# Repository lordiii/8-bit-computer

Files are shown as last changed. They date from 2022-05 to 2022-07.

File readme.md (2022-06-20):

# Custom 8 Bit Computer

The KiCad project in this folder contains a high-level view of the Computer using KiCad's subschematics. 

_TODO: High-Level View as PDF_

### Folder Structure
- [Parts](parts/): Contains KiCad 5 schematics of each of the computers parts.
- [Instructions](instructions/): FPGA implementation of the instruction decoder, as well as the list of instructions 

### Credits
- [Ben Eater](https://eater.net). Some parts are based on his 8 Bit Computer

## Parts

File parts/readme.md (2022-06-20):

### TODO
This folder will contain a list of each sub-part and a brief description

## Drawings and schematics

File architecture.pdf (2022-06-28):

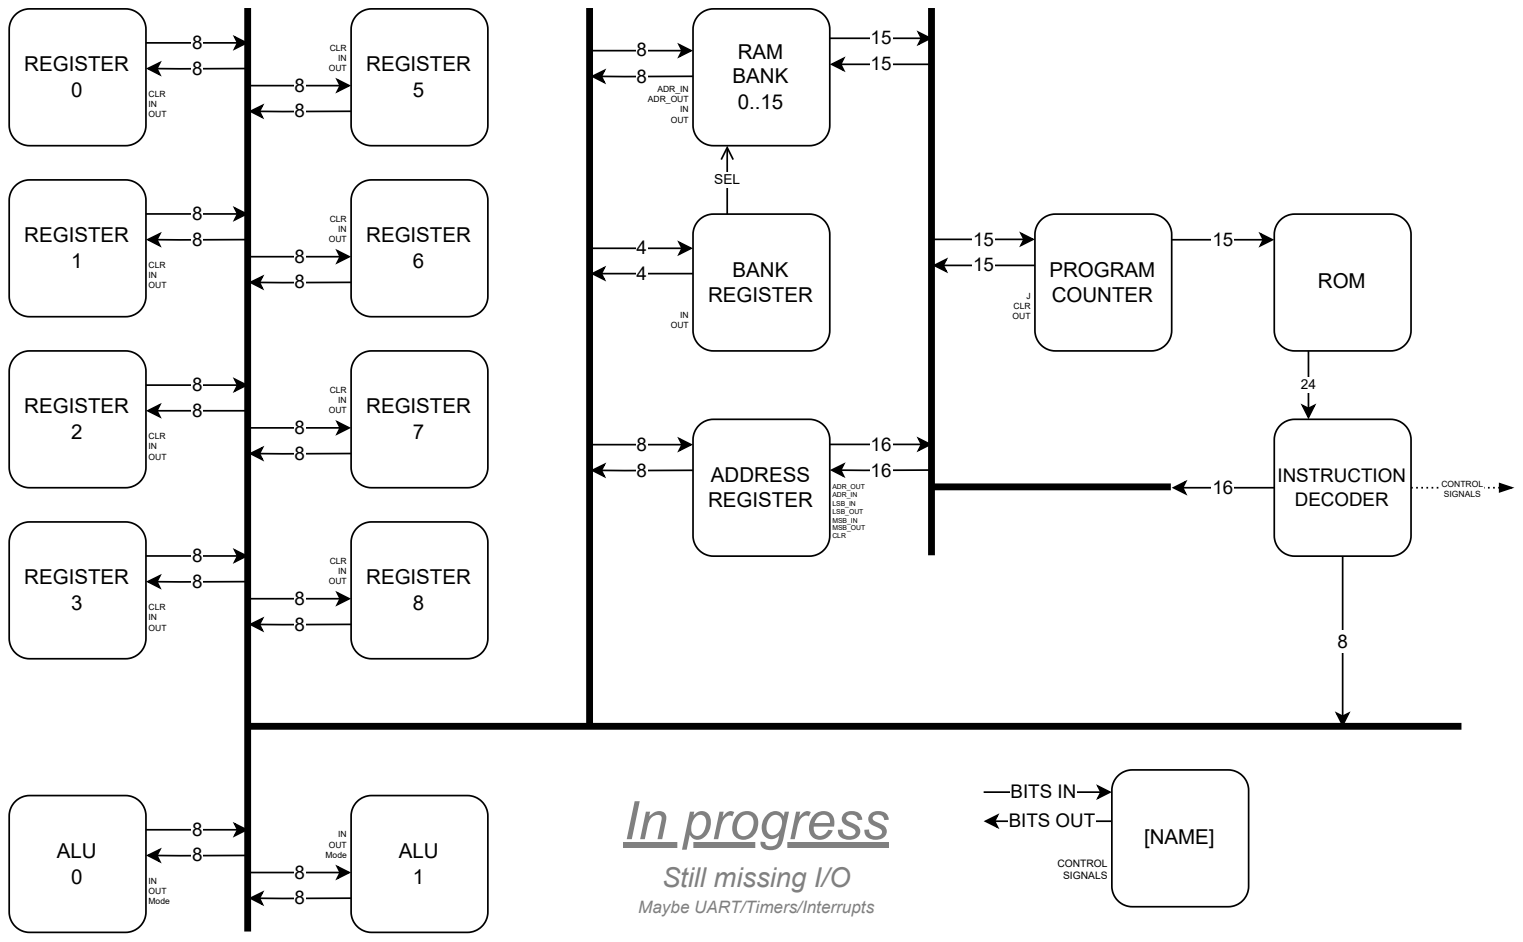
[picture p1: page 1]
REGISTER 0; REGISTER 1; REGISTER 2; REGISTER 5; REGISTER 6; REGISTER 7; REGISTER 3; REGISTER 8; ALU 0; ALU 1; CLR IN OUT; IN OUT; RAM BANK 0..15; IN OUT Mode; INSTRUCTION DECODER; In progress; ADDRESS REGISTER; ADR_OUT ADR_IN LSB_IN LSB_OUT MSB_IN MSB_OUT CLR; [NAME]; CONTROL SIGNALS; BITS IN BITS OUT; BANK; REGISTER; ROM; ADR_IN ADR_OUT IN OUT; SEL; J CLR OUT; PROGRAM COUNTER

Still missing I/O
Maybe UART/Timers/Interrupts

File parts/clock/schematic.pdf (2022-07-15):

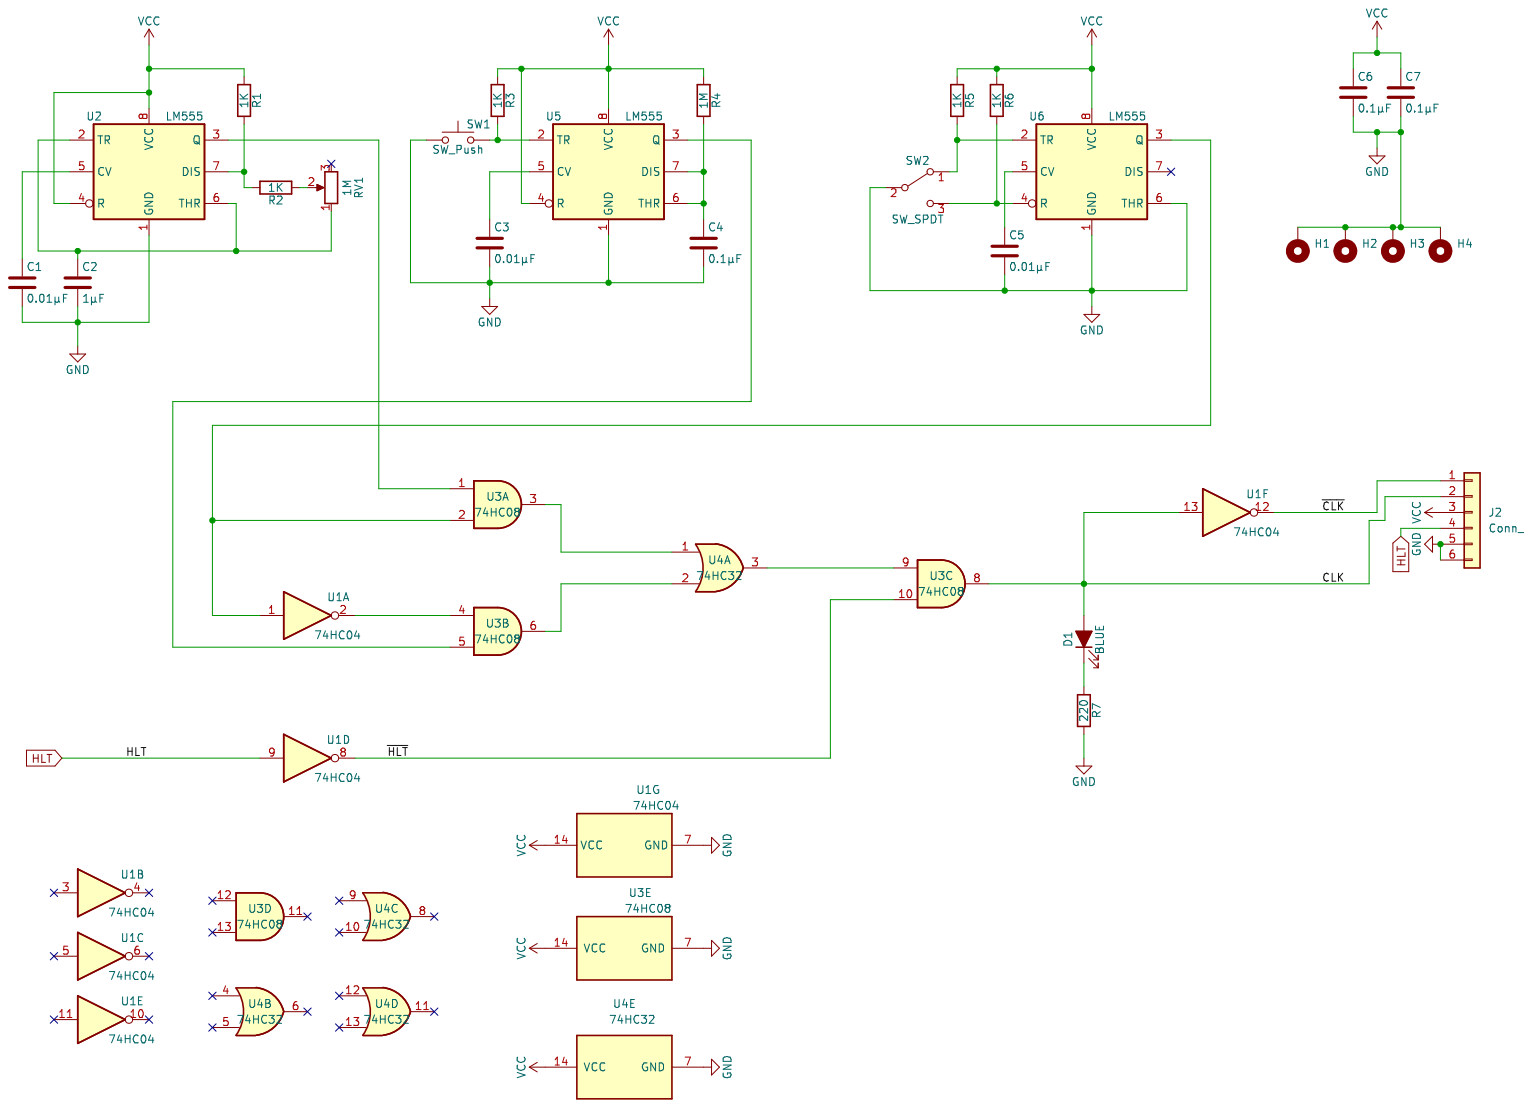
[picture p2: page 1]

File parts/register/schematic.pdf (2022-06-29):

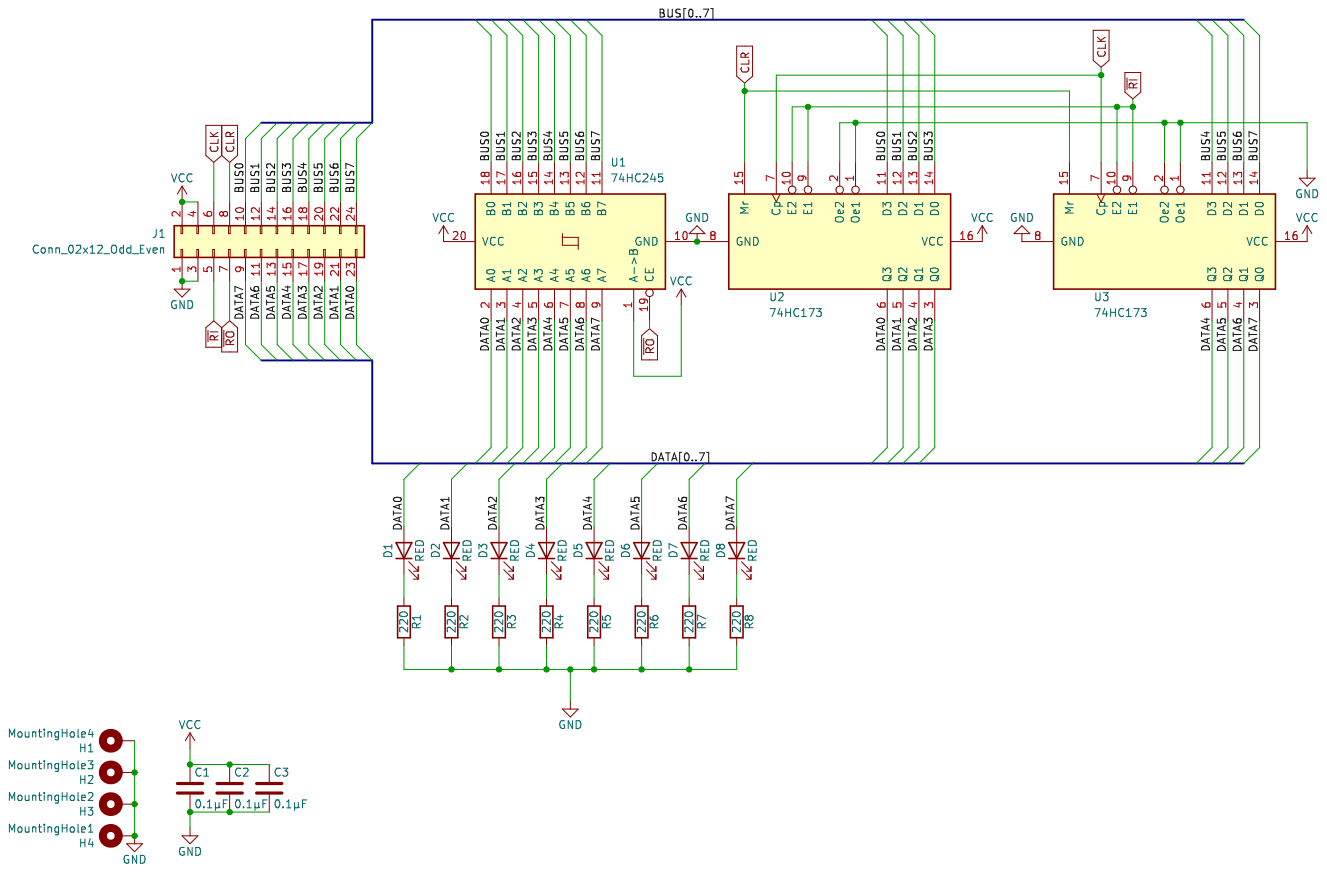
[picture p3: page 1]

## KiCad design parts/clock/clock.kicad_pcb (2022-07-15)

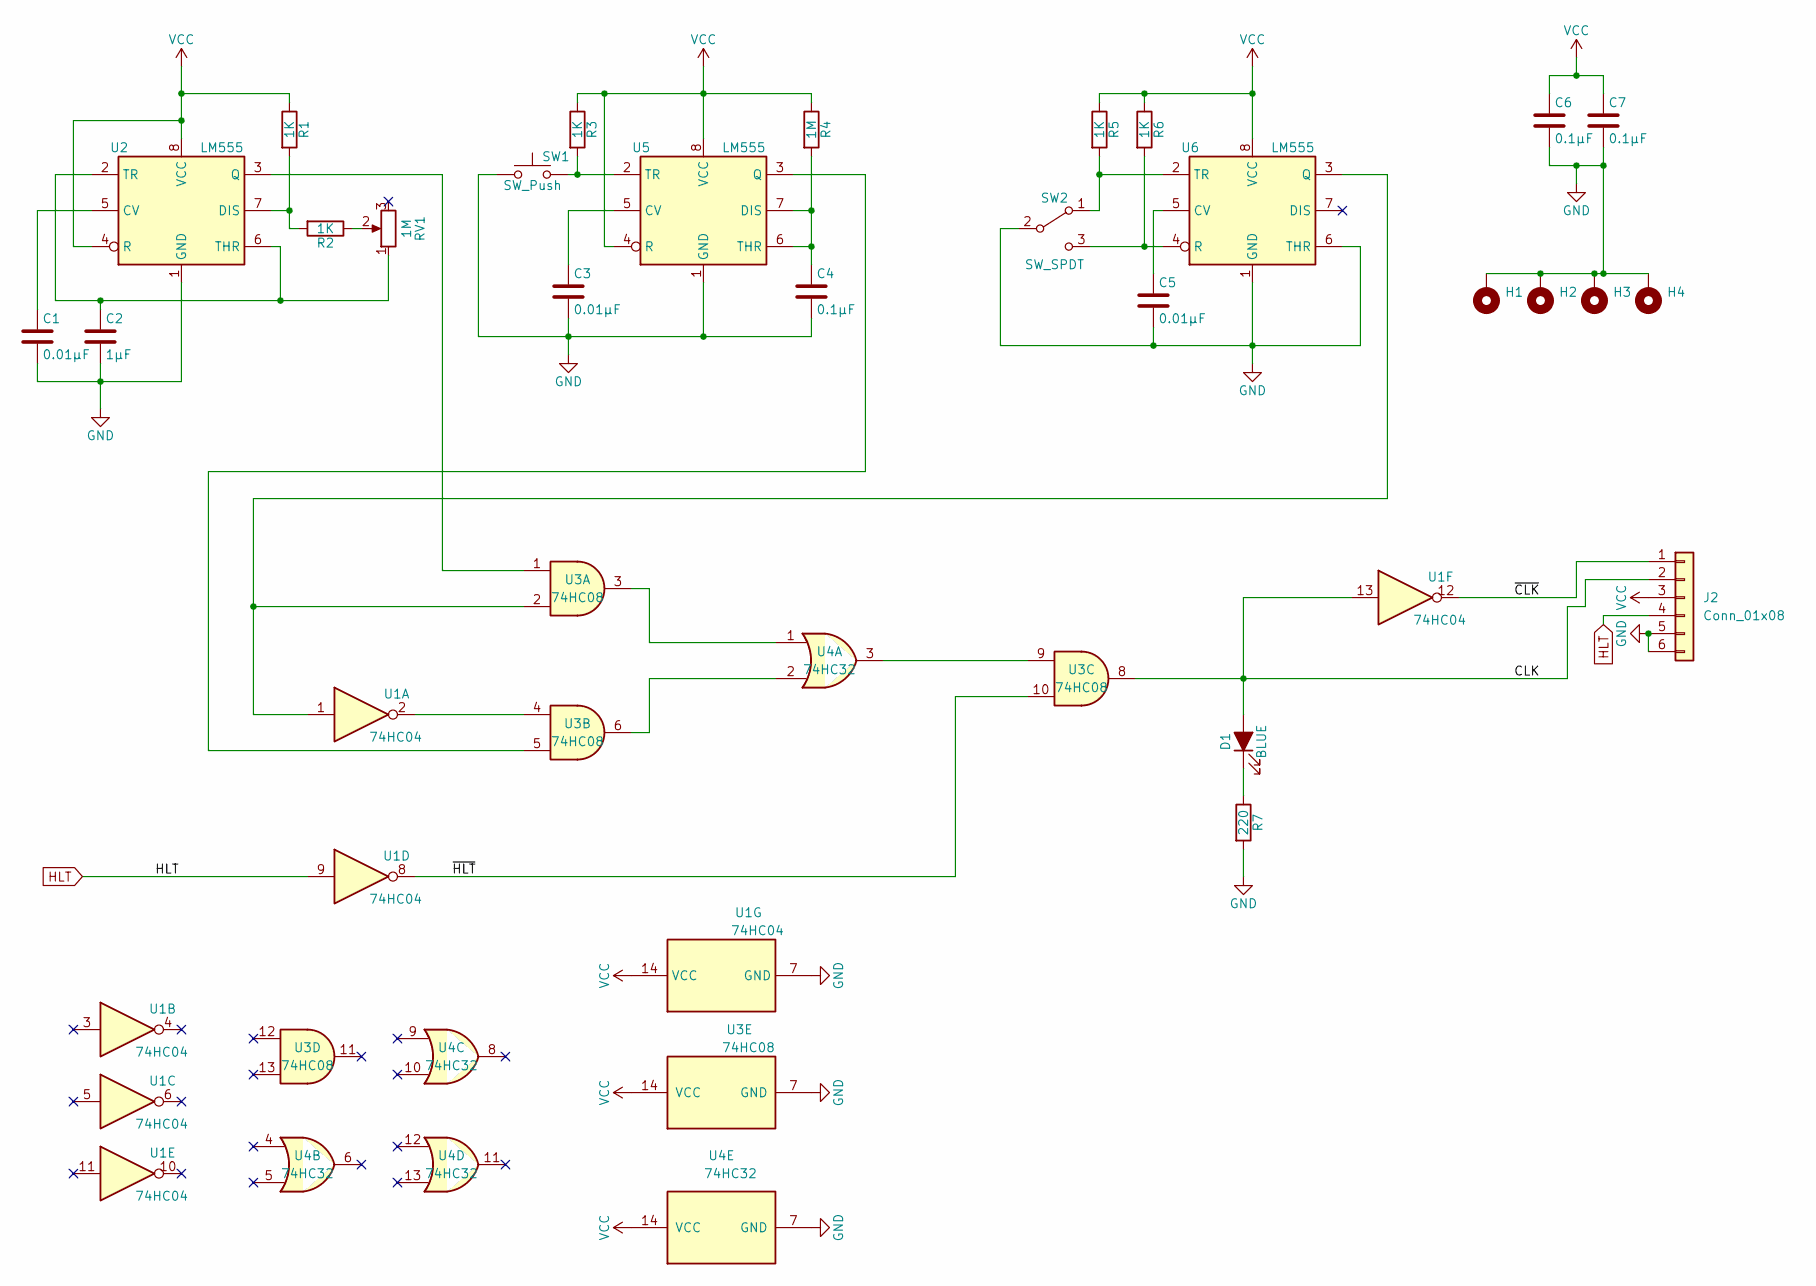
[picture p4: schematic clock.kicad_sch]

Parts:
C1, C3, C5: 0.01µF; C_0805_2012Metric
C2: 1µF; C_0805_2012Metric
C4, C6, C7: 0.1µF; C_0805_2012Metric
D1: BLUE; LED_0805_2012Metric
H1, H2, H3, H4: MountingHole_Pad; MountingHole_2.2mm_M2_DIN965_Pad
J2: Conn_01x08; IDC-Header_2x03_P2.54mm_Vertical
R1, R2, R3, R5, R6: 1K; R_0805_2012Metric
R4: 1M; R_0805_2012Metric
R7: 220; R_0805_2012Metric
RV1: 1M; Potentiometer_ACP_CA9-V10_Vertical
SW1: SW_Push; SW_PUSH-12mm
SW2: SW_SPDT; switch
U1: 74HC04; SO-14_3.9x8.65mm_P1.27mm
U2, U5, U6: LM555; SO-8_3.9x4.9mm_P1.27mm
U3: 74HC08; SO-14_3.9x8.65mm_P1.27mm
U4: 74HC32; SO-14_3.9x8.65mm_P1.27mm

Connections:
/CLK: D1.2 (A), J2.2, U1.13, U3.8
/~CLK: J2.1, U1.12
/~HLT: U1.8, U3.10
GND: C1.2, C2.2, C3.2, C4.2, C5.2, C6.2, C7.2, H1.1, H2.1, H3.1, H4.1, J2.5, J2.6, R7.2, SW1.1, SW2.2 (B), U1.7 (GND), U2.1 (GND), U3.7 (GND), U4.7 (GND), U5.1 (GND), U6.1 (GND), U6.6 (THR)
HLT: J2.4, U1.9
unnamed: C1.1, U2.5 (CV)
unnamed: C2.1, RV1.1, U2.2 (TR), U2.6 (THR)
unnamed: C3.1, U5.5 (CV)
unnamed: C4.1, R4.2, U5.6 (THR), U5.7 (DIS)
unnamed: C5.1, U6.5 (CV)
unnamed: D1.1 (K), R7.1
unnamed: R1.2, R2.2, U2.7 (DIS)
unnamed: R2.1, RV1.2
unnamed: R3.2, SW1.2, U5.2 (TR)
unnamed: R5.2, SW2.1 (A), U6.2 (TR)
unnamed: R6.2, SW2.3 (C), U6.4 (R)
unnamed: U1.1, U3.2, U6.3 (Q)
unnamed: U1.2, U3.4
unnamed: U2.3 (Q), U3.1
unnamed: U3.3, U4.1
unnamed: U3.5, U5.3 (Q)
unnamed: U3.6, U4.2
unnamed: U3.9, U4.3
VCC: C6.1, C7.1, J2.3, R1.1, R3.1, R4.1, R5.1, R6.1, U1.14 (VCC), U2.4 (R), U2.8 (VCC), U3.14 (VCC), U4.14 (VCC), U5.4 (R), U5.8 (VCC), U6.8 (VCC)

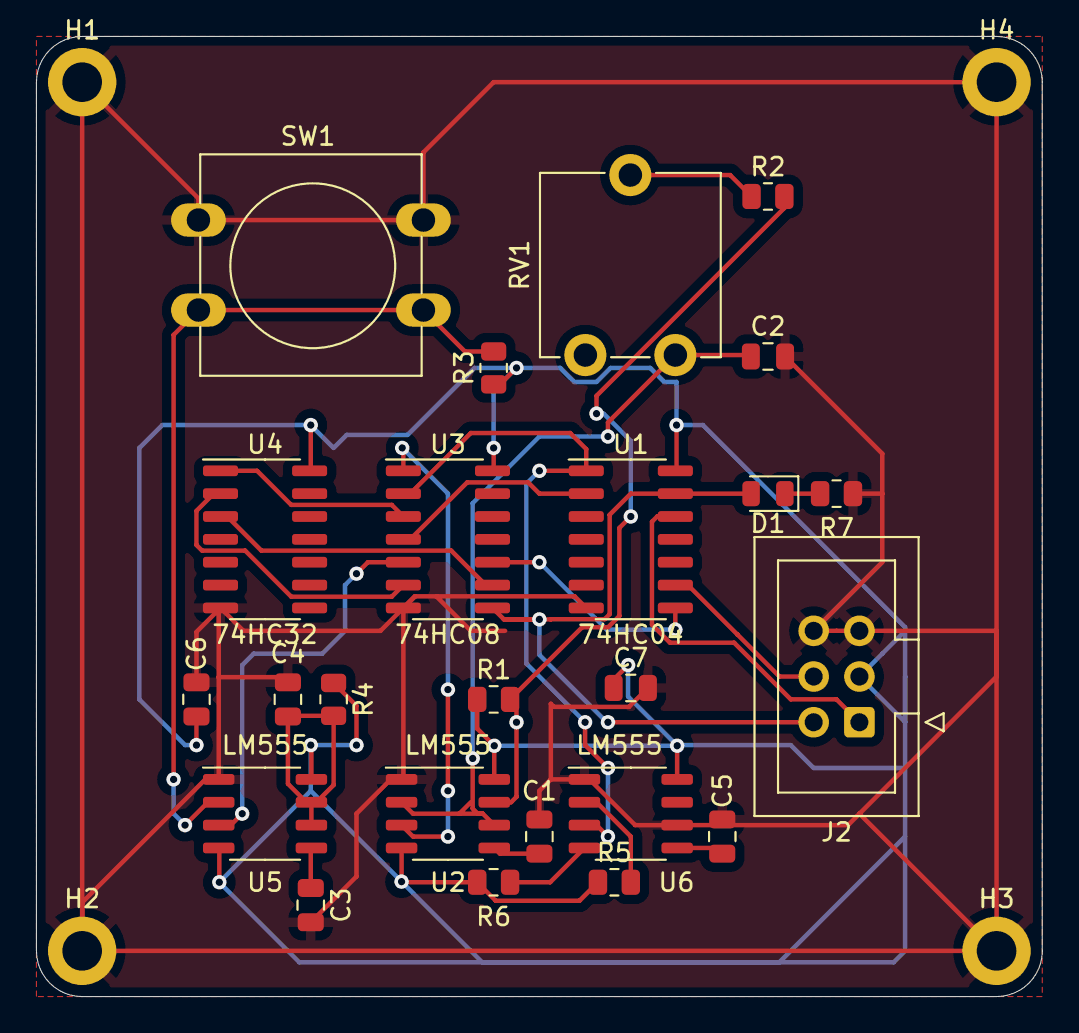
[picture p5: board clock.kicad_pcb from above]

Board: 2 copper layers, 55.9 x 53.3 mm, 28 parts (0 on the bottom side), 24 nets.

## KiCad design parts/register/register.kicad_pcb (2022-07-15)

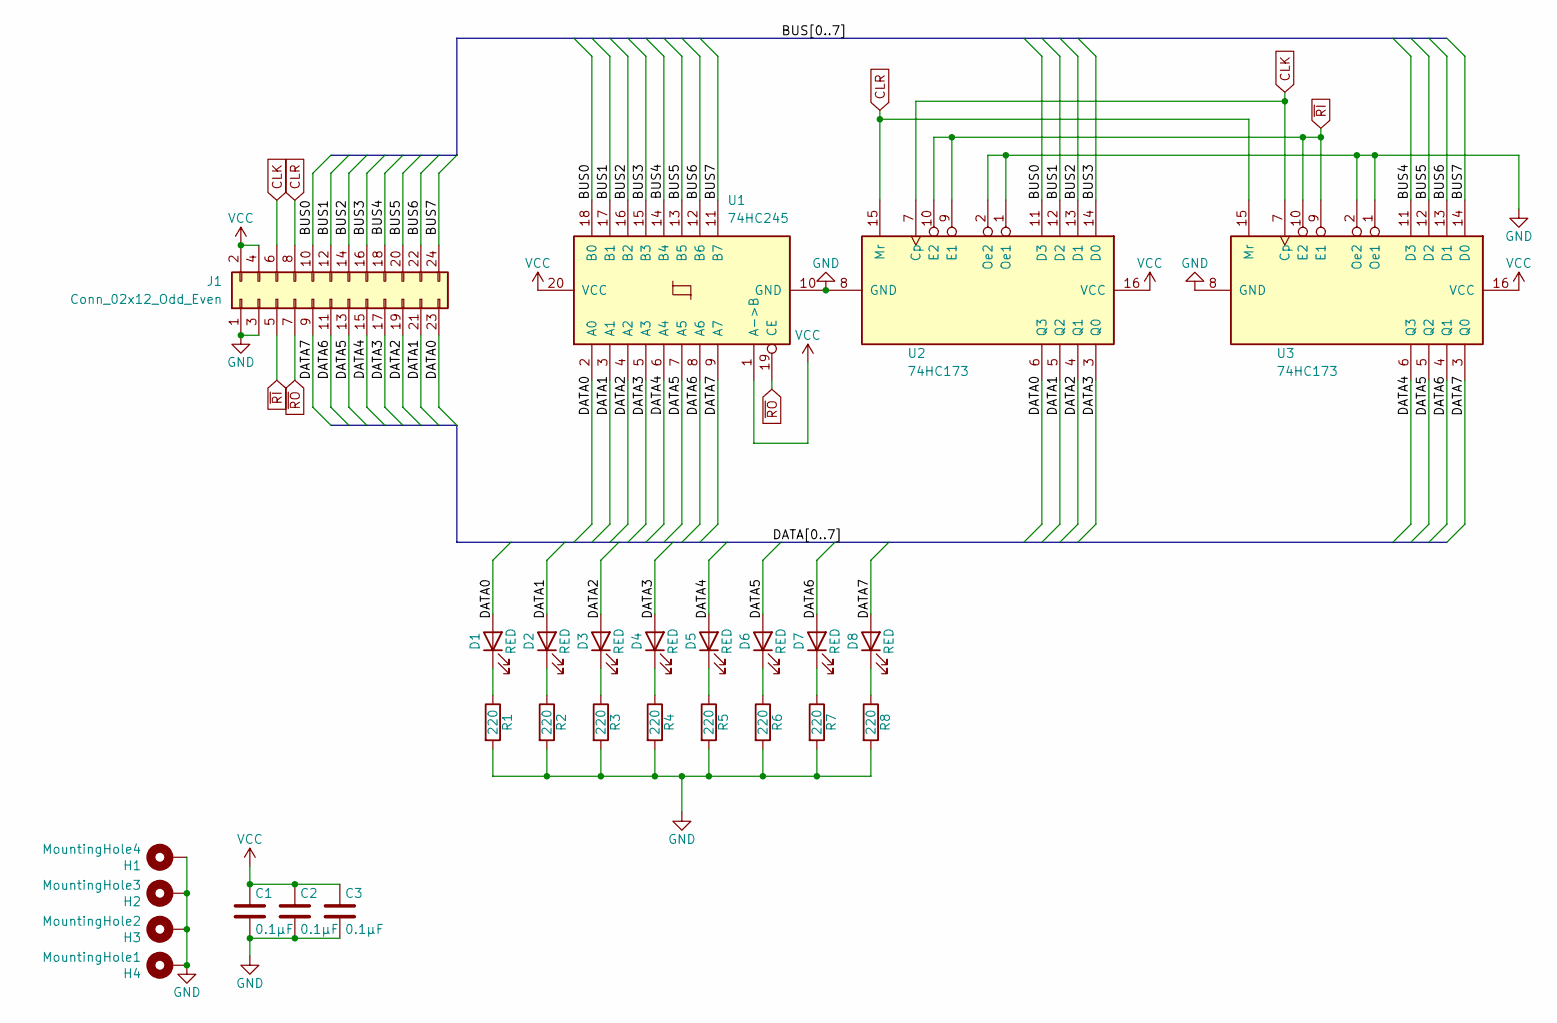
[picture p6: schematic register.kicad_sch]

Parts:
C1, C2, C3: 0.1µF; C_0805_2012Metric
D1, D2, D3, D4, D5, D6, D7, D8: RED; LED_0805_2012Metric
H1: MountingHole4; MountingHole_2.2mm_M2_Pad_Via
H2: MountingHole3; MountingHole_2.2mm_M2_Pad_Via
H3: MountingHole2; MountingHole_2.2mm_M2_Pad_Via
H4: MountingHole1; MountingHole_2.2mm_M2_Pad_Via
J1: Conn_02x12_Odd_Even; IDC-Header_2x12_P2.54mm_Vertical
R1, R2, R3, R4, R5, R6, R7, R8: 220; R_0805_2012Metric
U1: 74HC245; TSSOP-20_4.4x6.5mm_P0.65mm
U2, U3: 74HC173; SOIC-16_3.9x9.9mm_P1.27mm

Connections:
/BUS0: J1.10, U1.18 (B0), U2.11 (D3)
/BUS1: J1.12, U1.17 (B1), U2.12 (D2)
/BUS2: J1.14, U1.16 (B2), U2.13 (D1)
/BUS3: J1.16, U1.15 (B3), U2.14 (D0)
/BUS4: J1.18, U1.14 (B4), U3.11 (D3)
/BUS5: J1.20, U1.13 (B5), U3.12 (D2)
/BUS6: J1.22, U1.12 (B6), U3.13 (D1)
/BUS7: J1.24, U1.11 (B7), U3.14 (D0)
/DATA0: D1.2 (A), J1.23, U1.2 (A0), U2.6 (Q3)
/DATA1: D2.2 (A), J1.21, U1.3 (A1), U2.5 (Q2)
/DATA2: D3.2 (A), J1.19, U1.4 (A2), U2.4 (Q1)
/DATA3: D4.2 (A), J1.17, U1.5 (A3), U2.3 (Q0)
/DATA4: D5.2 (A), J1.15, U1.6 (A4), U3.6 (Q3)
/DATA5: D6.2 (A), J1.13, U1.7 (A5), U3.5 (Q2)
/DATA6: D7.2 (A), J1.11, U1.8 (A6), U3.4 (Q1)
/DATA7: D8.2 (A), J1.9, U1.9 (A7), U3.3 (Q0)
CLK: J1.6, U2.7 (Cp), U3.7 (Cp)
CLR: J1.8, U2.15 (Mr), U3.15 (Mr)
GND: C1.2, C2.2, C3.2, H1.1, H2.1, H3.1, H4.1, J1.1, J1.3, R1.2, R2.2, R3.2, R4.2, R5.2, R6.2, R7.2, R8.2, U1.10 (GND), U2.1 (Oe1), U2.2 (Oe2), U2.8 (GND), U3.1 (Oe1), U3.2 (Oe2), U3.8 (GND)
unnamed: D1.1 (K), R1.1
unnamed: D2.1 (K), R2.1
unnamed: D3.1 (K), R3.1
unnamed: D4.1 (K), R4.1
unnamed: D5.1 (K), R5.1
unnamed: D6.1 (K), R6.1
unnamed: D7.1 (K), R7.1
unnamed: D8.1 (K), R8.1
VCC: C1.1, C2.1, C3.1, J1.2, J1.4, U1.1 (A->B), U1.20 (VCC), U2.16 (VCC), U3.16 (VCC)
~RI: J1.5, U2.9 (E1), U2.10 (E2), U3.9 (E1), U3.10 (E2)
~RO: J1.7, U1.19 (CE)

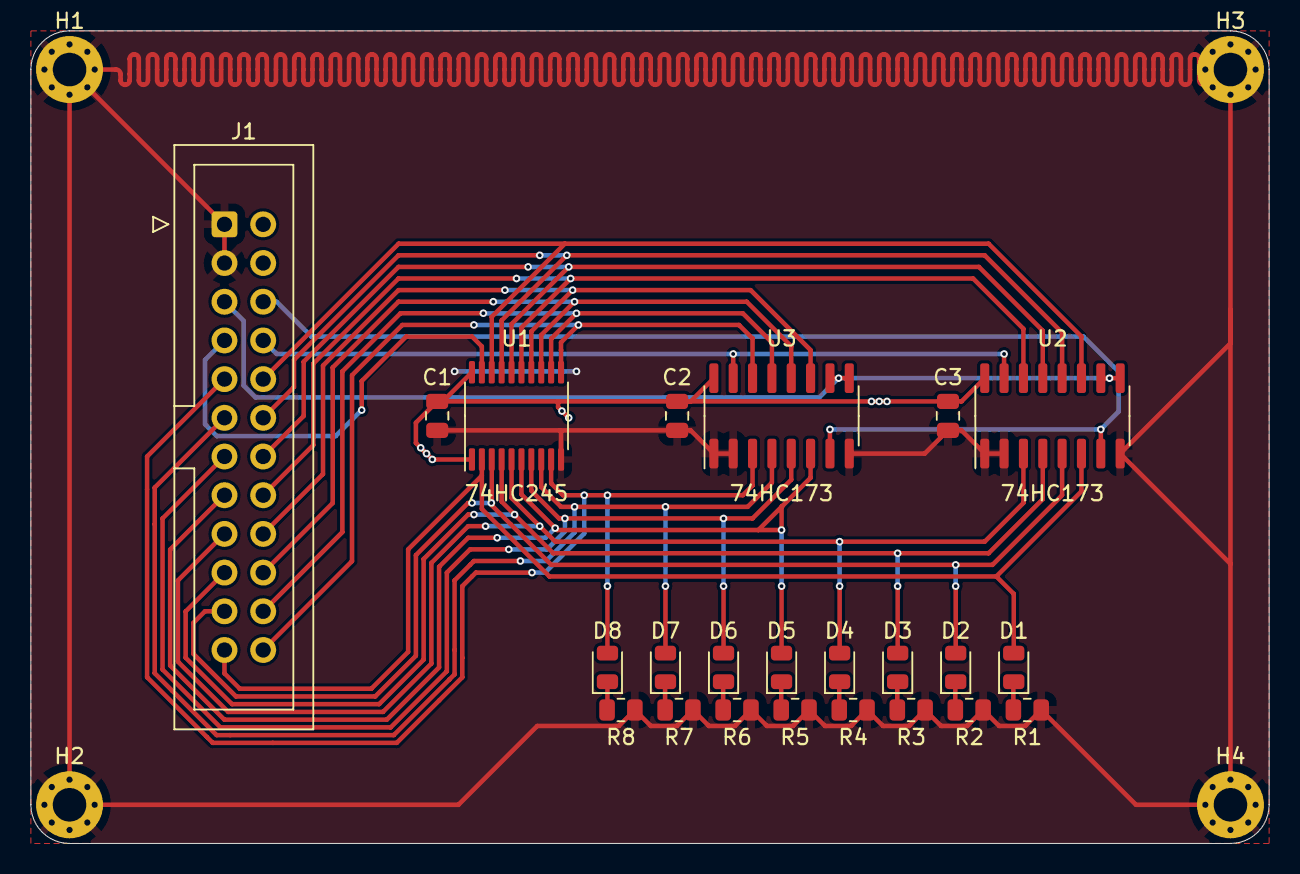
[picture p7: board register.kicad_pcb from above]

Board: 2 copper layers, 81.3 x 53.3 mm, 27 parts (0 on the bottom side), 30 nets.

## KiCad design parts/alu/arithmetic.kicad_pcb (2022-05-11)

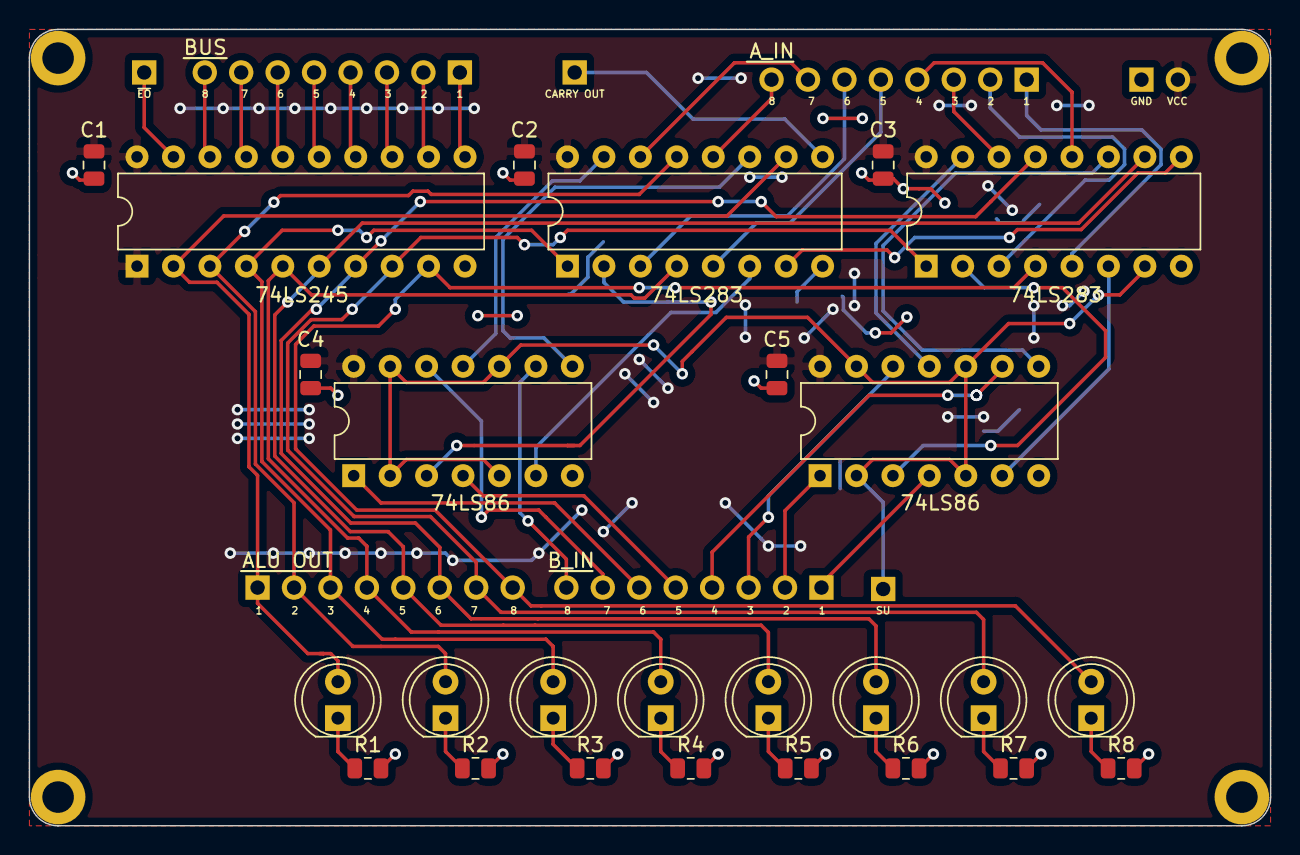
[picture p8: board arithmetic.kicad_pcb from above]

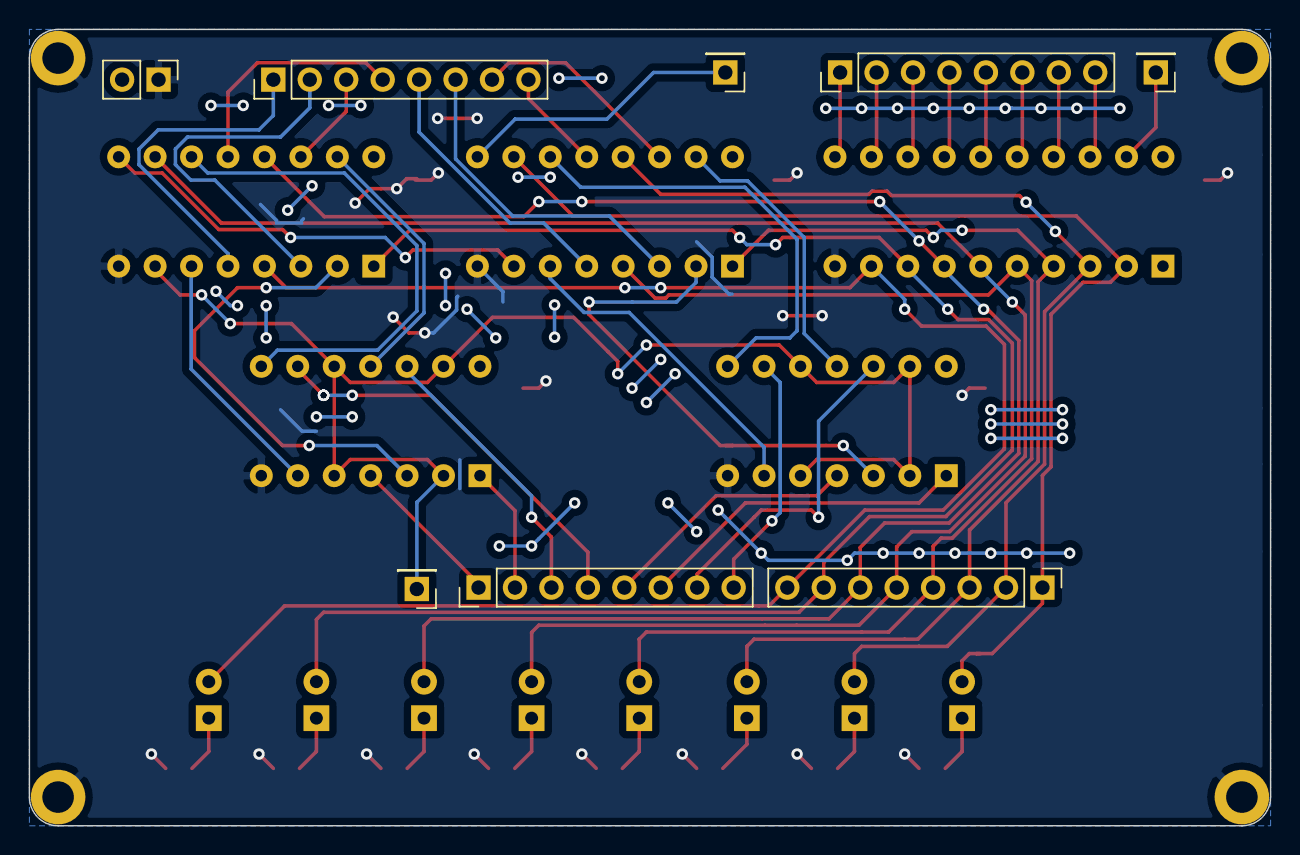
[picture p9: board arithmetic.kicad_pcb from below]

Board: 2 copper layers, 86.5 x 55.5 mm, 38 parts (8 on the bottom side), 54 nets.

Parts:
C1, C2, C3, C4, C5: 0.1µF; C_0805_2012Metric
D1, D2, D3, D4, D5, D6, D7, D8: RED; LED_D5.0mm
H1, H2, H3, H4: MountingHole_Pad; MountingHole_2.2mm_M2_DIN965_Pad
J1: ~{EO}; PinHeader_1x01_P2.54mm_Vertical
J2: SU; PinHeader_1x01_P2.54mm_Vertical
J3: BUS; PinHeader_1x08_P2.54mm_Vertical
J4: B_IN; PinHeader_1x08_P2.54mm_Vertical
J5: CARRY OUT; PinHeader_1x01_P2.54mm_Vertical
J6: A_IN; PinHeader_1x08_P2.54mm_Vertical
J7: ALU OUT; PinHeader_1x08_P2.54mm_Vertical
J8: Conn_01x02; PinHeader_1x02_P2.54mm_Vertical
R1, R2, R3, R4, R5, R6, R7, R8: 220; R_0805_2012Metric
U1, U3: 74LS86; DIP-14_W7.62mm
U2: 74LS245; DIP-20_W7.62mm
U4, U5: 74LS283; DIP-16_W7.62mm

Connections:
/A1: J6.8, U4.12 (A4)
/A2: J6.7, U4.14 (A3)
/A3: J6.6, U4.3 (A2)
/A4: J6.5, U4.5 (A1)
/A5: J6.4, U5.12 (A4)
/A6: J6.3, U5.14 (A3)
/A7: J6.2, U5.3 (A2)
/A8: J6.1, U5.5 (A1)
/B1: J4.8, U1.9
/B2: J4.7, U1.12
/B3: J4.6, U1.1
/B4: J4.5, U1.4
/B5: J4.4, U3.9
/B6: J4.3, U3.12
/B7: J4.2, U3.1
/B8: J4.1, U3.4
/COUT: J5.1, U4.9 (C4)
/OUT1: D1.2 (A), J7.1, U2.2 (A0), U4.10 (S4)
/OUT2: D2.2 (A), J7.2, U2.3 (A1), U4.13 (S3)
/OUT3: D3.2 (A), J7.3, U2.4 (A2), U4.1 (S2)
/OUT4: D4.2 (A), J7.4, U2.5 (A3), U4.4 (S1)
/OUT5: D5.2 (A), J7.5, U2.6 (A4), U5.10 (S4)
/OUT6: D6.2 (A), J7.6, U2.7 (A5), U5.13 (S3)
/OUT7: D7.2 (A), J7.7, U2.8 (A6), U5.1 (S2)
/OUT8: D8.2 (A), J7.8, U2.9 (A7), U5.4 (S1)
/SU: J2.1, U1.2, U1.5, U1.10, U1.13, U3.2, U3.5, U3.10, U3.13, U5.7 (C0)
/~EO: J1.1, U2.19 (CE)
GND: C1.2, C2.2, C3.2, C4.2, C5.2, H1.1, H2.1, H3.1, H4.1, J8.1, R1.2, R2.2, R3.2, R4.2, R5.2, R6.2, R7.2, R8.2, U1.7 (GND), U2.10 (GND), U3.7 (GND), U4.8 (GND), U5.8 (GND)
unnamed: D1.1 (K), R1.1
unnamed: D2.1 (K), R2.1
unnamed: D3.1 (K), R3.1
unnamed: D4.1 (K), R4.1
unnamed: D5.1 (K), R5.1
unnamed: D6.1 (K), R6.1
unnamed: D7.1 (K), R7.1
unnamed: D8.1 (K), R8.1
unnamed: J3.1, U2.11 (B7)
unnamed: J3.2, U2.12 (B6)
unnamed: J3.3, U2.13 (B5)
unnamed: J3.4, U2.14 (B4)
unnamed: J3.5, U2.15 (B3)
unnamed: J3.6, U2.16 (B2)
unnamed: J3.7, U2.17 (B1)
unnamed: J3.8, U2.18 (B0)
unnamed: U1.3, U4.2 (B2)
unnamed: U1.6, U4.6 (B1)
unnamed: U1.8, U4.11 (B4)
unnamed: U1.11, U4.15 (B3)
unnamed: U3.3, U5.2 (B2)
unnamed: U3.6, U5.6 (B1)
unnamed: U3.8, U5.11 (B4)
unnamed: U3.11, U5.15 (B3)
unnamed: U4.7 (C0), U5.9 (C4)
VCC: C1.1, C2.1, C3.1, C4.1, C5.1, J8.2, U1.14 (VCC), U2.1 (A->B), U2.20 (VCC), U3.14 (VCC), U4.16 (VCC), U5.16 (VCC)

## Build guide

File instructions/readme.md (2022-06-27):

aThis folder contains both the list of instruction, as well as an FPGA implementation on an iCE40HX8K-CT256.

# Instructions

## Layout

- Most Significant 8-bits reserved for instruction
- Least Significant 16-bits reserved for instruction arguments

## Instruction Groups

- Rra/Rrb: any readable register address
- Rwa/Rwb: any writable register address
- D16: 16-bit address
- D8: 8-bit address

### Miscellaneous Instructions

| Opcode | Assembly  | Arguments | Description |
|---|:---:|:---|:---|
| 0x00 | NOP | | No operation |
| 0x11 | IMMEDIATE | Rwa | Load constant into Rwa |
| 0xFF | HLT | | No operation |

### Transfer Instructions 0x20 - 0x3F

| Opcode | Assembly | Arguments | Description |
|---|:---:|:---|:---|
| 0x20 | PUSH | Rra | Write Rra to stack, decrement stack pointer |
| 0x21 | POP | Rwa | Copy value from stack into Rwa, increment stack pointer |
| 0x22 | PEEK | Rwa | Copy value from stack into Rwa |
| 0x23 | MOV | Rra, Rwa  | Copy Rra to Rwa |
| 0x24 | MEMW | D16 | Copy R0 to memory address D16 |
| 0x25 | MEML | D16 | Copy memory address D16 to R0 |

### Arithmetic Instructions 0x40 - 0x5F

- Arithmetic results are stored in ALU Register

| Opcode | Assembly | Arguments | Description |
|---|:---:|:---|:---|
| 0x40 | ADD | Rra, Rrb  | Add Rrb to Rra |
| 0x41 | SUB | Rra, Rrb  | Subtract Rrb from Rra |
| 0x42 | MUL | Rra, Rrb  | Multiply Rra by Rrb |
| 0x43 | OR | Rra, Rrb  | Logical OR between Rra and Rrb  |
| 0x44 | AND | Rra, Rrb  | Logical AND between Rra and Rrb |
| 0x45 | XOR | Rra, Rrb  | Logical XOR between Rra and Rrb |
| 0x46 | NOT | Rra | Logical not on Rra |
| 0x47 | LSL | Rra | Logical left shift Rra by 1 |
| 0x48 | LSR | Rra | Logical light shift Rra by 1 |

### Branch/Jump Instructions 0x60-0x7F

| Opcode | Assembly | Arguments | Description |
|---|:---:|:---|:---|
| 0x60 | JMP | D16 | Unconditional jump |
| 0x61 | JC | D16 | Jump if carry bit is set |
| 0x62 | JZ | D16 | Jump if zero bit is set  |
| 0x63 | JN | D16 | Jump if negative |

### CPU Flags

| Short | Name |
|---|:---:|
| C |  Carry Flag |
| Z | Zero Flag |
| N | Negative Flag |

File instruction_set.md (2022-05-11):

## Layout

- Most Significant 8-bits reserved for instruction
- Least Significant 16-bits reserved for instruction arguments

# Instructions

- Rra/Rrb: any readable register address
- Rwa/Rwb: any writable register address
- D16: 16-bit address
- D8: 8-bit address

## Miscellaneous 0x00 - 0x0F

| Opcode | Assembly  | Arguments | Description |
|---|:---:|:---|:---|
| 0x00 | NOP | | No operation |
| 0x01 | IMMEDIATE | Rwa | Load constant into Rwa |
| 0xFF | HLT | | No operation |

## Transfer 0x10 - 0x1F

| Opcode | Assembly | Arguments | Description |
|---|:---:|:---|:---|
| 0x10 | PUSH | Rra | Write Rra to stack, decrement stack pointer |
| 0x11 | POP | Rwa | Copy value from stack into Rwa, increment stack pointer |
| 0x12 | PEEK | Rwa | Copy value from stack into Rwa |
| 0x13 | MOV | Rra, Rwa  | Copy Rra to Rwa |
| 0x14 | MEMW | Rra, D8 | Copy Rra to memory address Ah |
| 0x15 | MEML | Rwa, D8 | Copy memory address Ah to Rwa |

## Arithmetic 0x20 - 0x2F

- Arithmetic results are stored in ALU Register

| Opcode | Assembly | Arguments | Description |
|---|:---:|:---|:---|
| 0x20 | ADD | Rra, Rrb  | Add Rrb to Rra |
| 0x21 | SUB | Rra, Rrb  | Subtract Rrb from Rra |
| 0x22 | MUL | Rra, Rrb  | Multiply Rra by Rrb |
| 0x23 | OR | Rra, Rrb  | Logical OR between Rra and Rrb  |
| 0x24 | AND | Rra, Rrb  | Logical AND between Rra and Rrb |
| 0x25 | XOR | Rra, Rrb  | Logical XOR between Rra and Rrb |
| 0x26 | XOR | Rra | Logical not on Rra |
| 0x27 | LSL | Rra | Logical left shift Rra by 1 |
| 0x28 | LSR | Rra | Logical light shift Rra by 1 |

## Branch/Jump 0x30-0x3F

- Arithmetic results are stored in ALU Register

| Opcode | Assembly | Arguments | Description |
|---|:---:|:---|:---|
| 0x30 | JMP | D16 | Unconditional jump |
| 0x31 | JC | D16 | Jump if carry bit is set |
| 0x32 | JZ | D16 | Jump if zero bit is set  |
| 0x33 | JN | D16 | Jump if negative |

## CPU Flags

| Short | Name |
|---|:---:|
| C |  Carry Flag |
| Z | Zero Flag |
| N | Negative Flag |

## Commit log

2022-06-20 Start Pin Definition
2022-06-21 Update High Level
    [arithmetic.kicad_sch, bus_leds.kicad_sch, computer.kicad_sch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]
2022-06-27 Architecture v1
    [bus_leds.kicad_pcb, bus_leds.kicad_sch, computer.kicad_sch]
2022-06-28 SMD Register
    [register.kicad_pcb, register.kicad_sch]
2022-06-29 Create PCB for Register
    [register.kicad_pcb, register.kicad_sch]
2022-07-15 SMD Clock
    [clock.kicad_pcb, clock.kicad_sch, register.kicad_pcb]
